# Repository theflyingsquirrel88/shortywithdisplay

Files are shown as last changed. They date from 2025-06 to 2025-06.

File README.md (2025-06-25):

# shortywithdisplay
PCB Design for the ShortywithDisplay Project

This Project is based on the design from kripton2035 from eevblog.com
https://www.eevblog.com/forum/testgear/finding-short-on-motherboards-with-a-shorty-(with-display)/

I was fixing my laptop and thinking there is a short somewhere which is hard to pin point. I then came across this project shorty with display and am very imppressed by it. I saw everyone was soldering component onto breadbroad but no PCB was ever designed for this. I then decided to take some time to design a PCB for this so that everyone will have a easier live down the road.
This PCB is designed with KiCAD 9.0. I used mostly 0603 SMD with some through hold components. You may Thesewant to take a look at the original Project to get an idea of what this PCB is for.

These days, you can order PCB online for a really low price. This make DIY project much easier.
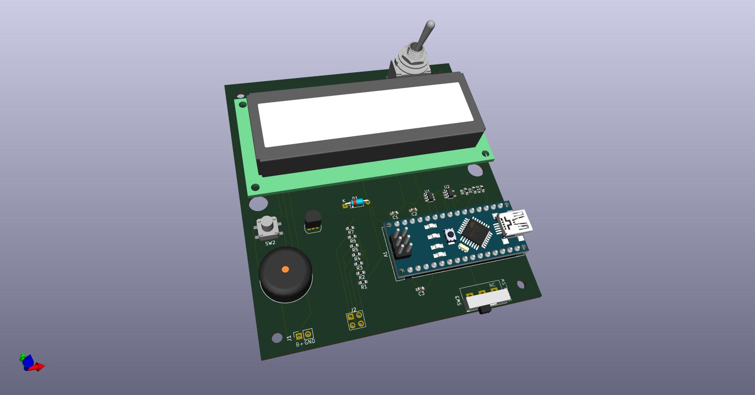
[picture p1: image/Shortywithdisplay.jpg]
3DModel

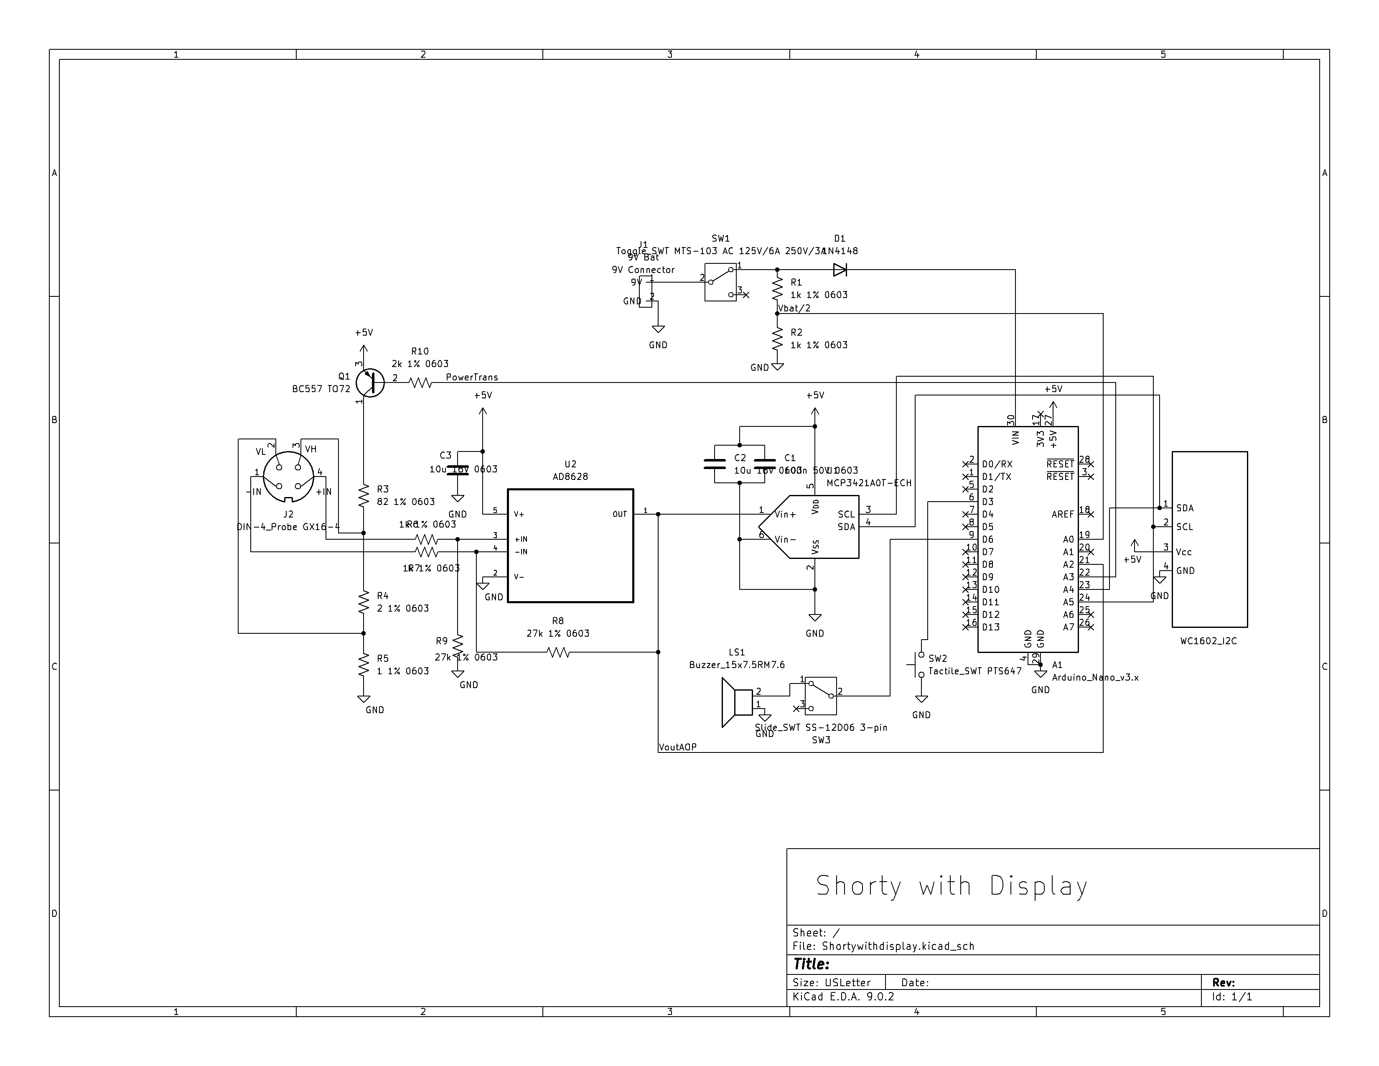
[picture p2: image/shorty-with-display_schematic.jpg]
schematic

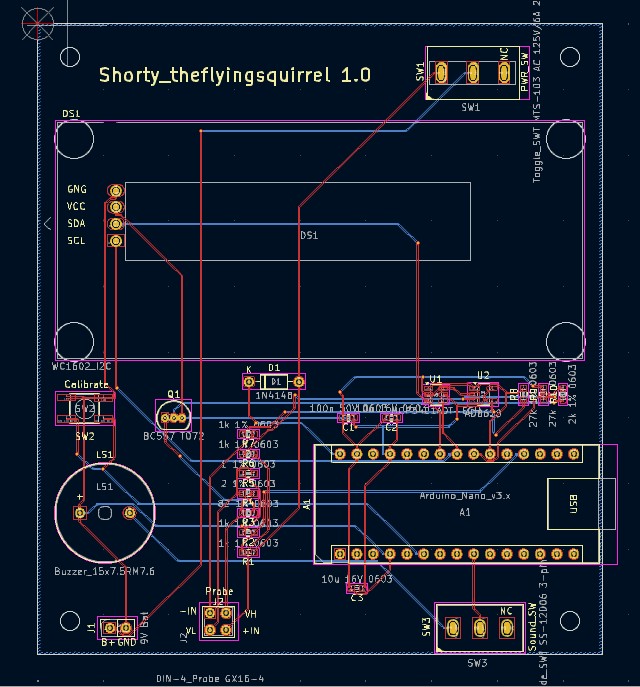
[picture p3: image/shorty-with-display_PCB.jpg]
PCB


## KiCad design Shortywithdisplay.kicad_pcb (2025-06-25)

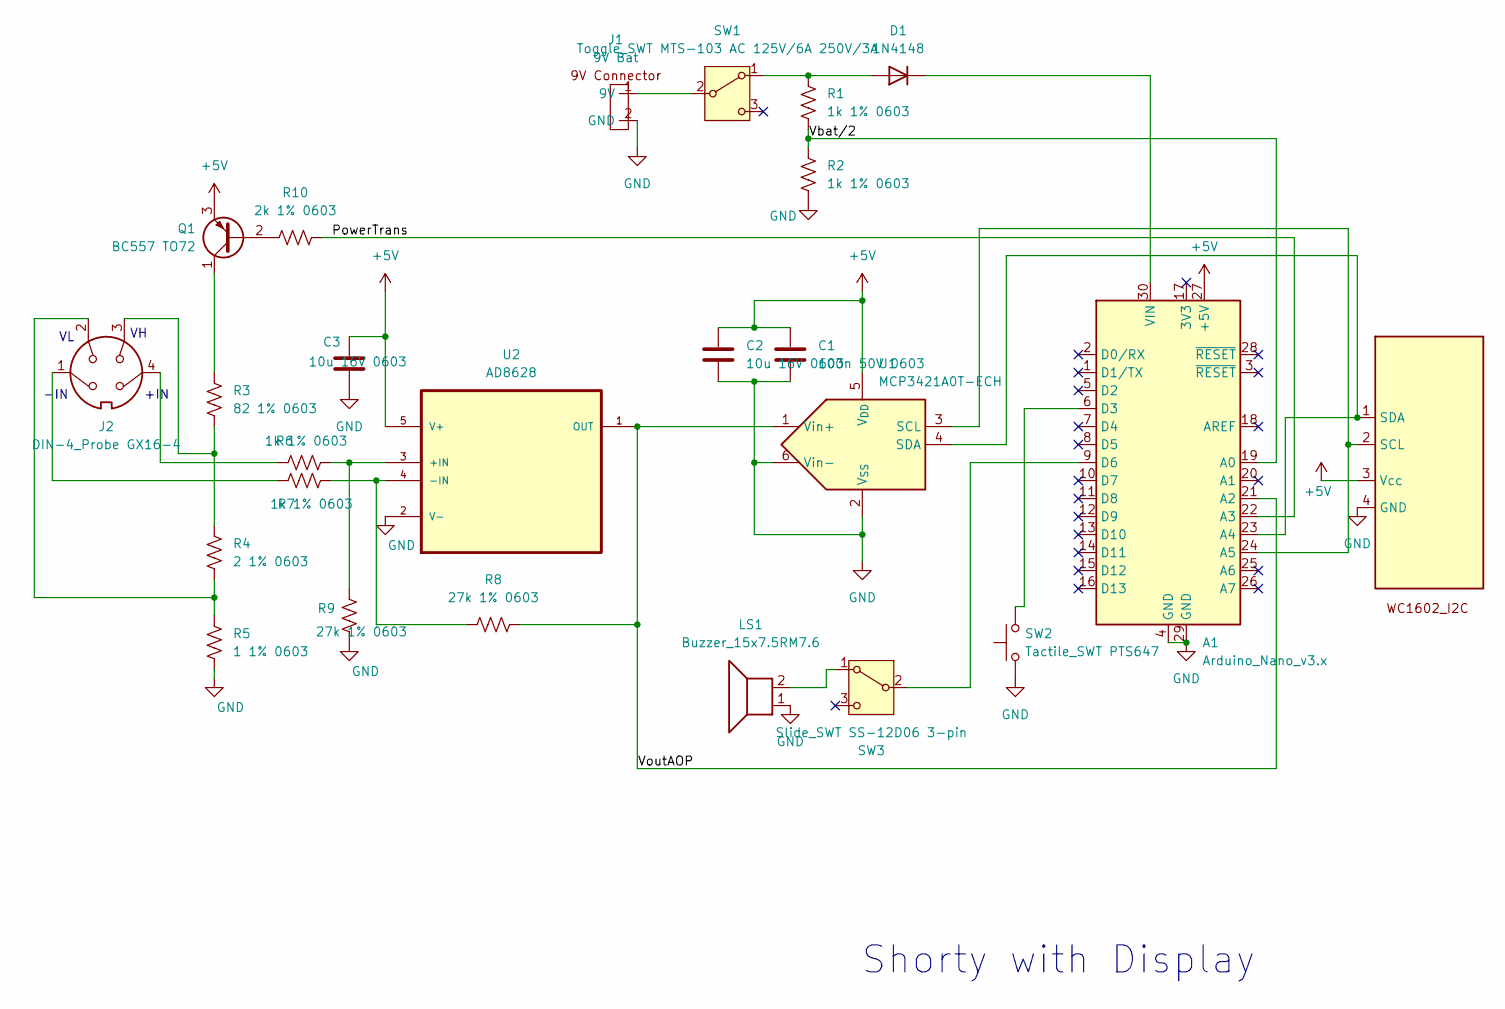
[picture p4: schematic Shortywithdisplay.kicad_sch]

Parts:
A1: Arduino_Nano_v3.x; Arduino_Nano_USB_nosilkscreen
C1: 100n 50V 0603; C_0603_1608Metric_Pad1.08x0.95mm_HandSolder
C2, C3: 10u 16V 0603; C_0603_1608Metric_Pad1.08x0.95mm_HandSolder
D1: 1N4148; D_DO-35_SOD27_P7.62mm_Horizontal
DS1: WC1602_I2C; WC1602A_I2C
J1: 9V Bat; PinSocket_1x02_P2.54mm_Vertical_NoModel
J2: DIN-4_Probe GX16-4; PinHeader_1x04_P2.54mm_Square
LS1: Buzzer_15x7.5RM7.6
Q1: BC557 TO72; TO-92_Inline
R1, R2, R6, R7: 1k 1% 0603; R_0603_1608Metric_Pad0.98x0.95mm_HandSolder
R3: 82 1% 0603; R_0603_1608Metric_Pad0.98x0.95mm_HandSolder
R4: 2 1% 0603; R_0603_1608Metric_Pad0.98x0.95mm_HandSolder
R5: 1 1% 0603; R_0603_1608Metric_Pad0.98x0.95mm_HandSolder
R8, R9: 27k 1% 0603; R_0603_1608Metric_Pad0.98x0.95mm_HandSolder
R10: 2k 1% 0603; R_0603_1608Metric_Pad0.98x0.95mm_HandSolder
SW1: Toggle_SWT MTS-103 AC 125V/6A 250V/3A; SW_toggle_1x03_P2.54mm_Vertical
SW2: Tactile_SWT PTS647; SW_Push_1P1T_4.26
SW3: Slide_SWT SS-12D06 3-pin; SW_slide_1x03_P2.54mm_Vertical
U1: MCP3421A0T-ECH; SOT-23-6
U2: AD8628; SOT-23-5_HandSoldering; MPN AD8628WARTZ-RL

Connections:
+5V: A1.27 (+5V), C1.1, C2.1, C3.1, DS1.3 (Vcc), Q1.3 (E), U1.5 (V_{DD}), U2.5 (V+)
/PowerTrans: A1.22 (A3), R10.2
/Vbat/2: A1.19 (A0), R1.2, R2.1
/VoutAOP: A1.21 (A2), R8.2, U1.1 (Vin+), U2.1 (OUT)
GND: A1.4 (GND), A1.29 (GND), C1.2, C2.2, C3.2, DS1.4 (GND), J1.2 (GND), LS1.1, R2.2, R5.2, R9.2, SW2.1, U1.2 (V_{SS}), U1.6 (Vin-), U2.2 (V-)
unnamed: A1.23 (A4), DS1.1 (SDA), U1.4 (SDA)
unnamed: A1.24 (A5), DS1.2 (SCL), U1.3 (SCL)
unnamed: A1.6 (D3), SW2.2
unnamed: A1.9 (D6), SW3.2 (B)
unnamed: A1.30 (VIN), D1.1 (K)
unnamed: D1.2 (A), R1.1, SW1.1 (A)
unnamed: J1.1 (9V), SW1.2 (B)
unnamed: J2.1, R7.1
unnamed: J2.2, R4.2, R5.1
unnamed: J2.3, R3.2, R4.1
unnamed: J2.4, R6.1
unnamed: Q1.2 (B), R10.1
unnamed: Q1.1 (C), R3.1
unnamed: LS1.2, SW3.1 (A)
unnamed: R6.2, R9.1, U2.3 (+IN)
unnamed: R7.2, R8.1, U2.4 (-IN)

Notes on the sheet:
-IN
+IN
Shorty with Display

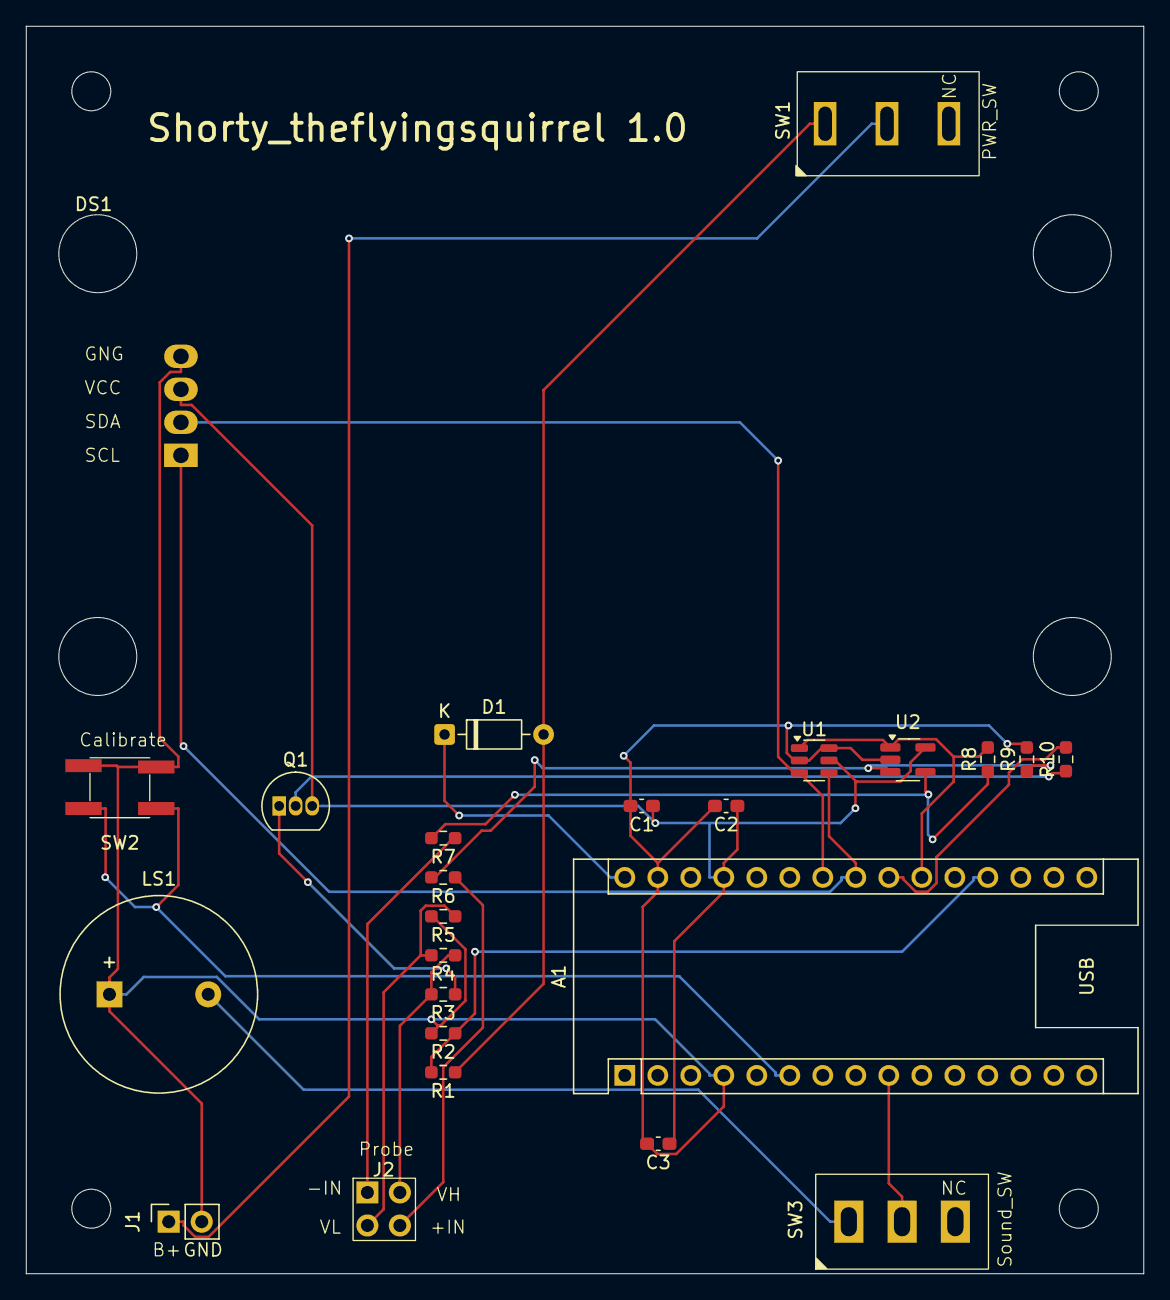
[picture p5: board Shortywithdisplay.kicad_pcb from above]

Board: 2 copper layers, 86.0 x 96.0 mm, 25 parts (0 on the bottom side), 21 nets.
